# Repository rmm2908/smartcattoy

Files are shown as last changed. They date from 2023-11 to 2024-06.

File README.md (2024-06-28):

# SmartCatToy

… is a toy controlled via a webapp to entertain our feline friends during our absence.

The idea behind this project is to provide a cheap alternative to expensive toys, with which you can provide entertainment for lonley single cats in flats.

## Must Have

- Spherical Toy
    - Moves around
    - Can receive input via network
- mobile App
    - connect toy to mobile app
    - control toy remotely
    - provides autopilot mode
- Back End
    - receive Data from App
    - send Data to Mobile app
- Database
    - Store Data from Backend
- Infrastructure
    - Running nodejs
    - Running database
    - reachable via internet

## Nice to Have

- replace autopilot (random generator) via inteligent movement detection
- add tail to toy for more interaction
- add sounds to toy
- add camera feed to app
- login (Database necessary)

## Platform Overview

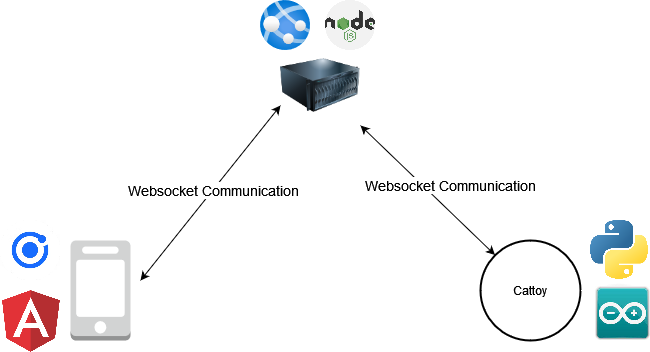
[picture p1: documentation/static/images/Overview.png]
Platform Overview
  

The client application is developed using Ionic 7 with Angular and can be deployed to iOS, Android and the Web.

The hardware toy is running a python script to receive data from the client and acts as the central inteligence hub of the hardware, housing the logic of the hardware and sends the commands over a Serial Interface to Arduino.

Arduino just receives the commands from python script on the Raspberry Pi and controls all sensors and motors.

Both the client application and the cattoy don't communicate directly to each other but to a server hosted on azure web application.

It is a NodeJS Express application that acts as an intermediary to establish connection between those two devices using WebSockets to enable low latency.

## Hardware Overview

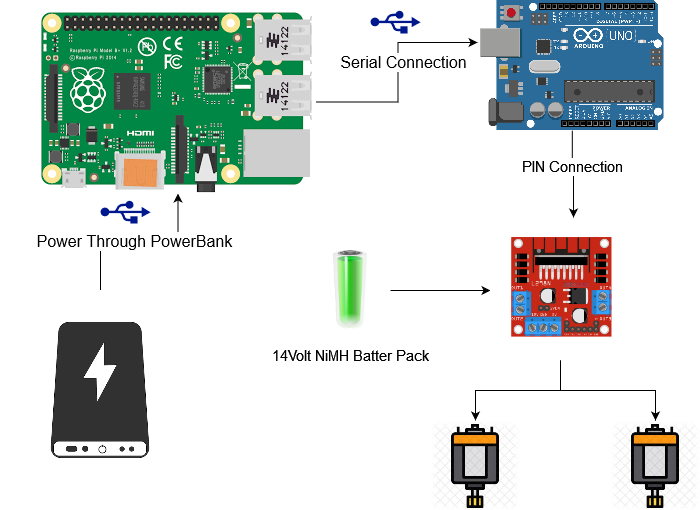
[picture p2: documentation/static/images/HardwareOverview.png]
Hardware Overview
  

A raspberry pi acts as the central logic hub, which is powered by a power bank.
It is directly connected to an Arduino Uno over a USB Serial Connection to establish bidirectional communication.

The Arudino receives all commands from the python script running on the raspberry to controll the motors attached to it. 
As the communication is bidirectional, it could send sensor data back to the raspberry, if those should be added.

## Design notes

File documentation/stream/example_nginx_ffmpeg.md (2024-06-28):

# Example setup for streaming web server
This example setup will provide the necessary configuration for a simple web server serving m3u8 video files using [nginx](https://nginx.org/en/).<br>
These instrunctions were last tested on a debian machine. Depending on which operating system you are using, some steps may vary.
## Setting up the web server
First, we will set up a nginx instance with which we will serve the video stream.<br>
### Install nginx
<b>Install nginx using apt</b><br>
``` sudo apt install nginx ```<br>
### Setup site
Once nginx is instaslled, only some basic configuration is necessary for a minimal nginx setup to provide a HLS stream. The configuration for nginx is located under "/etc/nginx". To serve the stream, we will create a new site under "/etc/nginx/sites-available/stream.config" using the following configuration:
```
server {
	listen 80 default_server;
	listen [::]:80 default_server;

	root /var/www/stream;

	index index.html index.htm index.nginx-debian.html;

	server_name _;

	location / {
		# CORS
		add_header 'Access-Control-Allow-Origin' '*' always;
		add_header 'Access-Control-Expose-Headers' 'Content-Length,Content-Range';
		add_header 'Access-Control-Allow-Headers' 'Range';

		types {
			application/vnd.apple.mpegurl m3u8;
			video/mp2t ts;
		}
		# First attempt to serve request as file, then
		# as directory, then fall back to displaying a 404.
		try_files $uri $uri/ =404;
		autoindex on;
	}
}
```
This configuration will a site on port 80 using the directory "/var/www/stream". In this directory, the video file for the stream should be placed.<br>
Different types for the video can be defined - by default, SmartCatToy uses m3u8.<br>
### Enable the site
To enable the site we just configured, we need to create a symbolic link to sites-enabled:
``` sudo ln -s /etc/nginx/sites-available/stream.conf /etc/nginx/sites-enabled/stream.conf ```<br>
After creating the link, nginx needs to be reloaded:<br>
``` sudo systemctl reload nginx ```
## Provide video resource for streaming
To provide a file that can be streamed via HLS from a camera installed on the toy, the toy needs to send a video stream to the server. For example, this could be achieved using [ffmpeg](https://ffmpeg.org/).
### Stream camera feed from toy to server
Using ffmpeg, the footage from an installed camera can be sent to the server. A [python script](../../raspberry/camera_client.py) running on the toy will send the camera footage to the server on port 8001 using UDP.
### Convert incoming stream to video file
On the server, we need to listen on this port and convert the incoming stream to a video file in the m3u8 format, so that it can be served using the nginx site we created.<br>
#### ffmpeg command to convert UDP stream to m3u8
This command will listen on the UDP port 8001 and convert the stream to a m3u8 and split the incoming frames into segments (.ts files):<br>
``` sudo ffmpeg -y -i udp://localhost:8001 -preset ultrafast -tune zerolatency -omit_video_pes_length 0 -g 90 -flags -global_header -fflags nobuffer -flags low_delay /var/www/stream/bucket/stream.m3u8 ```<br>
This command uses various parameters and presets to try to reduce the streaming delay caused by HLS streaming. Once the server starts to receive UDP packets on the specified port, ffmpeg will create a stream.m3u8 file and segment the incoming video feed into small .ts-files.
## Resulting HLS streaming resource
If the above instrunctions were all carried out, a video file will be created from the incoming camera feed and can be queried using HLS. If the exact configurations and folder structures were used, it will be available under ``` http://<server-address>/bucket/stream.m3u8 ```

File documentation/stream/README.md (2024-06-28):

# Stream
The SmartCatToy app provides the possibility of live streaming a camera feed from the toy.  It does this by querying a web server to stream a video using HLS (HTTP-Livestreaming). Therefore, a web server providing such a stream is needed for this feature to work.
## Requirements
* ### Web server
    A web server is needed to provide the video resource for the stream.
It is important that the video file can be accessed directly via URL (also consider CORS).
* ### Video ressource for streaming
    A video file in the correct format (default: m3u8) can be served through the web server to the app. SmartCatToy does this by sending the camera feed to the server using UDP. The server then converts the incoming UDP stream to the required video format.
### Example using nginx and ffmpeg
Instructions for setting up such a environment can be found [here](example_nginx_ffmpeg.md).

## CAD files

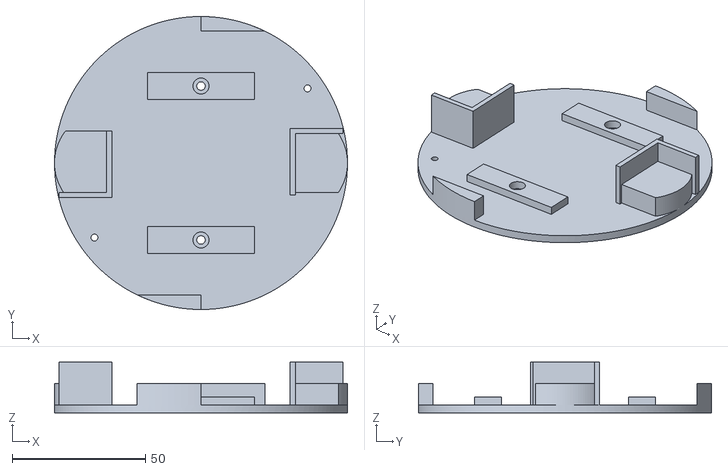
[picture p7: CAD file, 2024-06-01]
cad_models/board/version4/board_bot-Body.stl
110.0 x 110.0 x 19.0

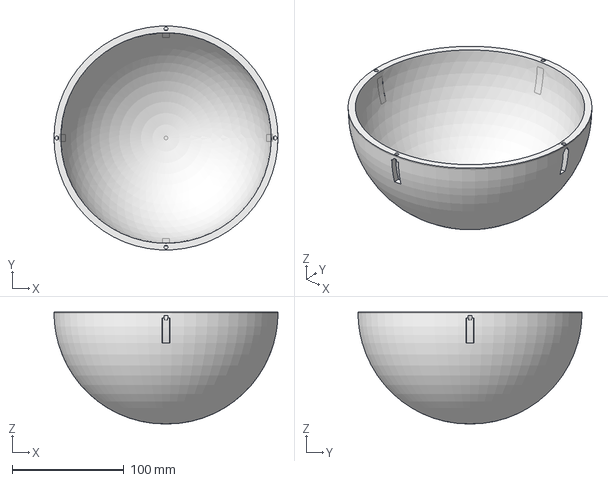
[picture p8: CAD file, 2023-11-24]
cad_models/sphere/version2/half_sphere.FCStd
200.0 x 199.9 x 100.0 mm

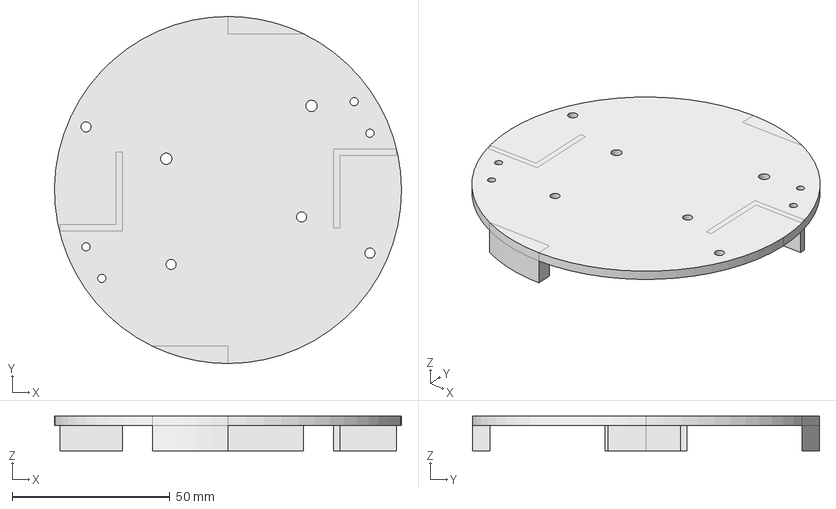
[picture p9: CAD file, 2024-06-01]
cad_models/board/version4/board_mid.FCStd
110.0 x 110.0 x 11.0 mm

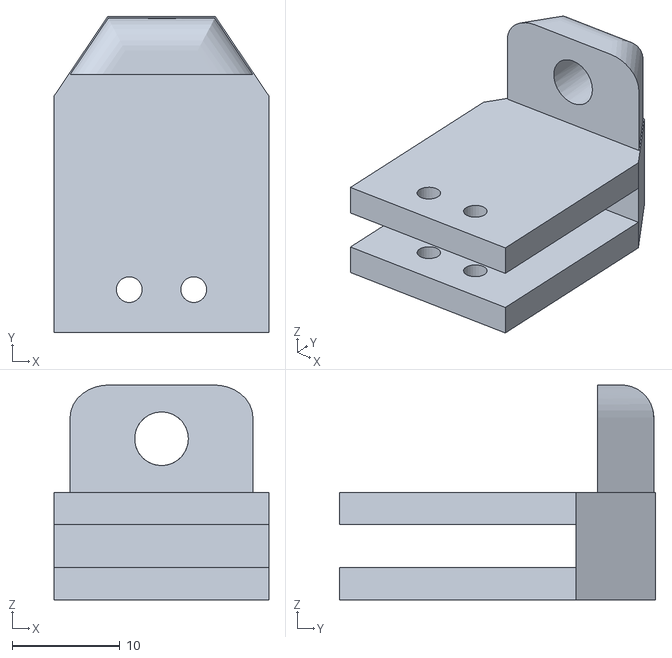
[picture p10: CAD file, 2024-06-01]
cad_models/board/version4/stabiliser_holder_neutral-Körper.stl
20.0 x 29.4 x 20.0

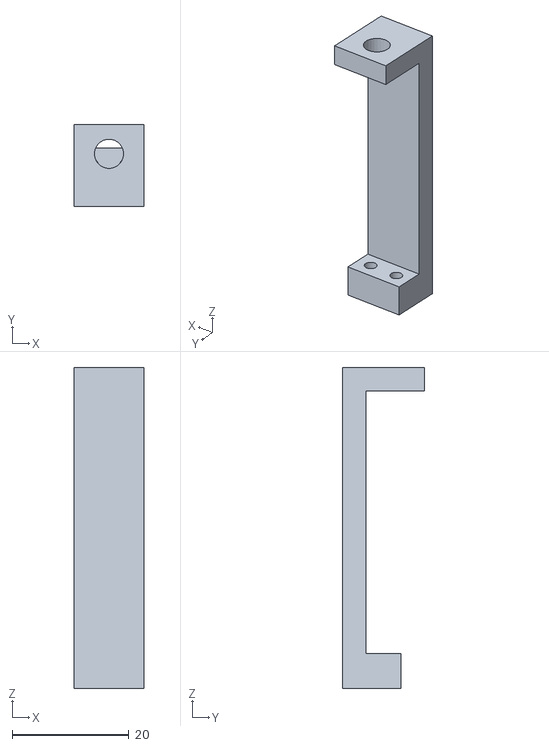
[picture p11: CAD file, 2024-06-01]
cad_models/board/version4/stabiliser_top-Body.stl
12.0 x 14.0 x 55.0

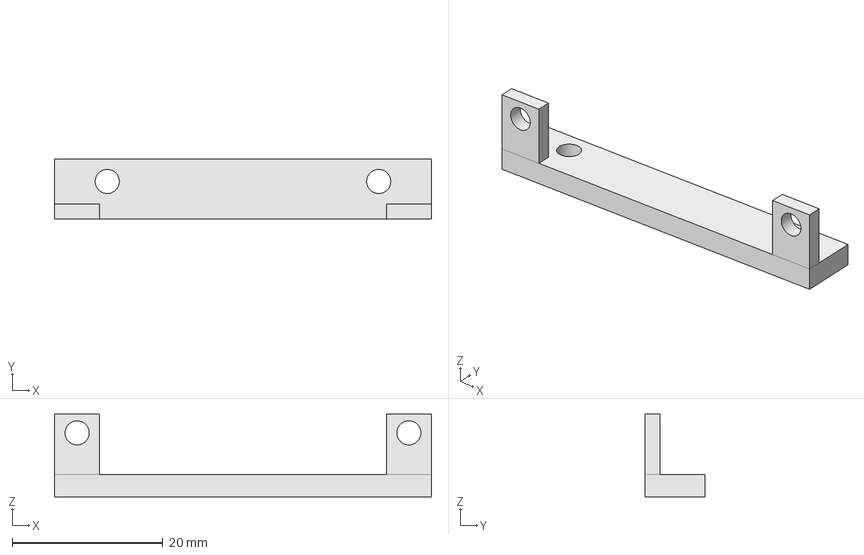
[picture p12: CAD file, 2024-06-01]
cad_models/board/version4/audio_holder_top.FCStd
50.0 x 8.00 x 11.0 mm

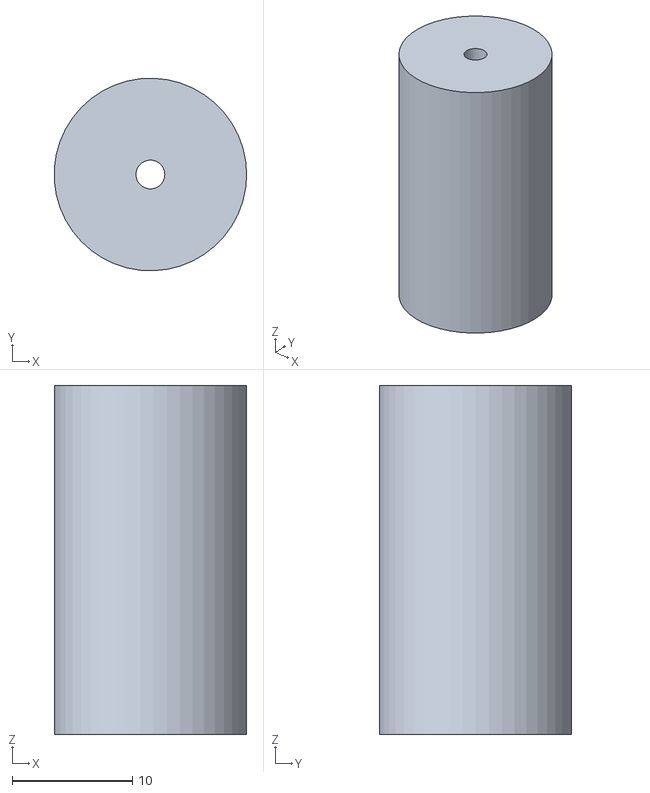
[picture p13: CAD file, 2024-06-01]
cad_models/board/version4/board_connector_top_mid-Body.stl
16.0 x 16.0 x 29.0

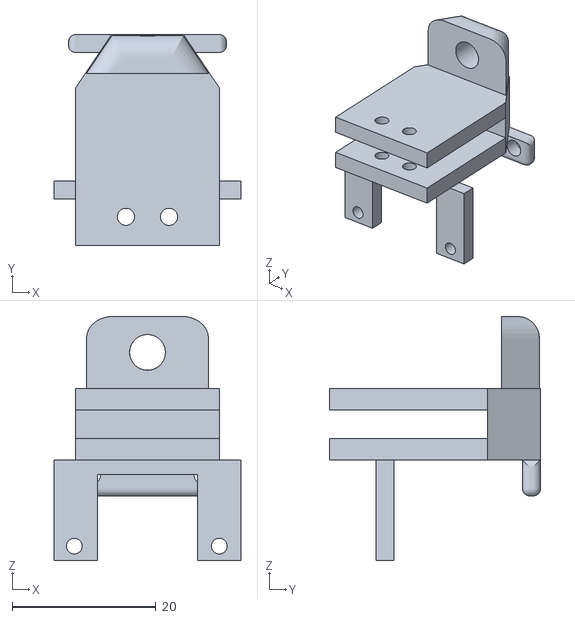
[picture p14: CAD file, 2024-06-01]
cad_models/board/version4/stabiliser_holder_sensors-Körper.stl
26.0 x 29.4 x 34.0

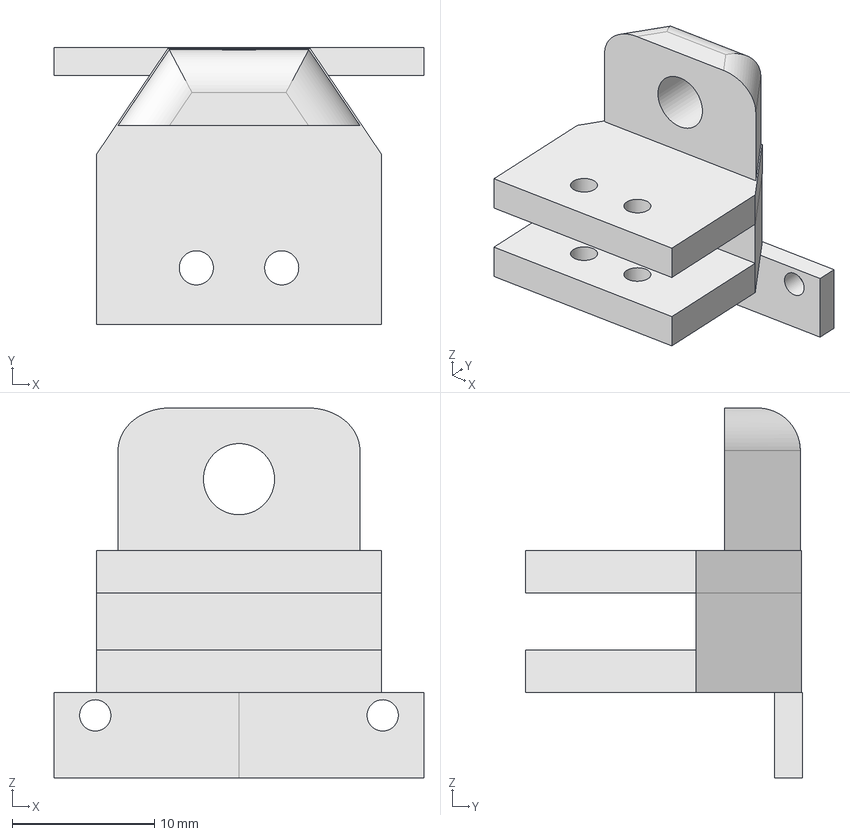
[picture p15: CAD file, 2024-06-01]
cad_models/board/version4/stabiliser_holder.FCStd
26.0 x 19.5 x 26.0 mm

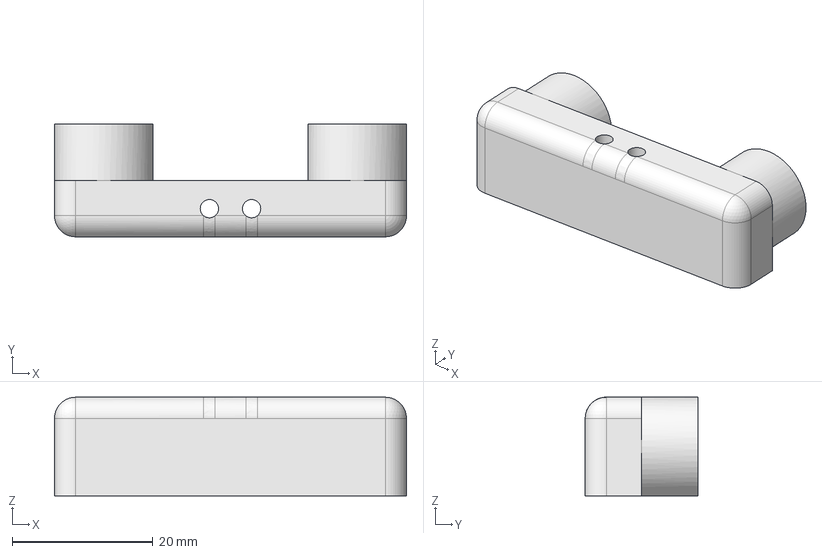
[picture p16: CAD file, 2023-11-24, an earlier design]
cad_models/board/version1/stabiliser_holder.FCStd
50.0 x 16.0 x 14.0 mm

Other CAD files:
cad_models/board/version4/stabiliser_holder_neutral.FCStd
cad_models/board/version4/stabiliser_holder-Body.stl
cad_models/board/version4/board_bot.FCStd
cad_models/board/version4/stabiliser_top.FCStd
cad_models/board/version4/board_connector_top_mid.FCStd
cad_models/board/version4/board_mid-Body.stl
cad_models/board/version4/stabiliser_holder_sensors.FCStd
cad_models/board/version2/board_bot.FCStd
cad_models/board/version1/adapted.FCStd
cad_models/board/version1/arduino_connector.FCStd
cad_models/board/version1/arduino_holder.FCStd
cad_models/board/version1/board_bot.FCStd
cad_models/board/version1/board_connector.FCStd
cad_models/board/version1/board_top.FCStd
cad_models/board/version1/cattoy2.FCStd
cad_models/board/version1/pad.FCStd
cad_models/board/version2/arduino_connector.FCStd
cad_models/board/version2/arduino_holder.FCStd
cad_models/board/version2/board_top.FCStd
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

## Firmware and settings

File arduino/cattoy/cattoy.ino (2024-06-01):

#include <Wire.h>
#include <VL6180X.h>

VL6180X sensor;

int ena = 11;
int in1 = 12;
int in2 = 10;

int enb = 5;
int in3 = 6;
int in4 = 7;
String input = "EMPTY";

int leftPower;
int leftReverse;
int rightPower;
int rightReverse;
int noUpdateCounter = 0;

char payload[64];

void setup() {
  Serial.begin(9600); 
  Wire.begin();

  sensor.init();
  sensor.configureDefault();
  sensor.setTimeout(500);

  pinMode(ena, OUTPUT);
  pinMode(in1, OUTPUT);
  pinMode(in2, OUTPUT);

  pinMode(enb, OUTPUT);
  pinMode(in3, OUTPUT);
  pinMode(in4, OUTPUT);
  
  }

int getIntFromString(String text) {
  return text.toInt();
}

void updateMotorPower(int leftPower, int rightPower) {

  if(leftPower > 255) {
    leftPower = 255;
  } 

  if(leftPower < 0) {
    leftPower = 0;
  }

  if(rightPower > 255) {
    rightPower = 255;
  }

  if(rightPower < 0) {
    rightPower = 0;
  }
  
  analogWrite(ena, leftPower);
  analogWrite(enb, rightPower);
}

void updateMotorDirection(int leftReverse, int rightReverse) {

  if(leftReverse == 0) {
    //Left
    digitalWrite(in1, HIGH);
    digitalWrite(in2, LOW);
  }

  if(leftReverse == 1) {
    //Left
    digitalWrite(in1, LOW);
    digitalWrite(in2, HIGH);
  }
  
  if(rightReverse == 0) {
    //Right
    digitalWrite(in3, LOW);
    digitalWrite(in4, HIGH);
  }

  if(rightReverse == 1) {
    //Right
    digitalWrite(in3, HIGH);
    digitalWrite(in4, LOW);
  }
}

void loop() {

  //Input -> 255,0,255,0 -> turned to 255 | 0 | 255 | 0
  if (Serial.available() > 0) {
    Serial.readStringUntil( '\n' ).toCharArray(payload, 64);
    leftPower = getIntFromString(strtok(payload, ","));
    leftReverse = getIntFromString(strtok(NULL, ","));
    rightPower = getIntFromString(strtok(NULL, ","));
    rightReverse = getIntFromString(strtok(NULL, ","));

    updateMotorPower(leftPower, rightPower);
    updateMotorDirection(leftReverse, rightReverse);
    noUpdateCounter = 0;
  } else {
    noUpdateCounter = noUpdateCounter + 1;
  }

  Serial.print(sensor.readRangeSingleMillimeters());
  //if (sensor.timeoutOccurred()) { Serial.print(" TIMEOUT"); }
  Serial.println();

  if(noUpdateCounter > 15) {
    updateMotorPower(0, 0);
  }

  delay(50);
}

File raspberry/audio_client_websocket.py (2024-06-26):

import websockets
import pygame
import asyncio
import json
import time
import os
import tempfile
import base64

# Initialize the pygame mixer for audio operations.
pygame.mixer.init()

# Get the event loop for the current context.
loop = asyncio.get_event_loop()

def play_audio(audio_file_path):
    """
    Load and play an audio file using pygame.

    Parameters:
        audio_file_path (str): The file system path to the audio file.
    """
    pygame.mixer.music.load(audio_file_path)
    pygame.mixer.music.play()

async def unload_audio():
    """
    Asynchronously monitors and unloads the audio track once it finishes playing.
    Continuously checks every second to see if the audio is still playing.
    """
    while True:
        await asyncio.sleep(1)
        if not pygame.mixer.music.get_busy():
            try:
                pygame.mixer.music.unload()
                print("Audio unloaded")
                break
            except Exception as e:
                print(f"Error unloading audio: {e}")
                break

async def receive_file(fileName, fileData):
    """
    Receives a base64 encoded file, decodes it, and writes it to the file system.

    Parameters:
        fileName (str): The name of the file to save.
        fileData (str): Base64 encoded data of the file.
    """
    if os.path.exists(fileName):
        os.remove(fileName)
    with open(fileName, "wb") as file:
        file.write(base64.b64decode(fileData))
        print(f"File received: {fileName}")

def handle_audio_command(content_obj):
    """
    Handles the command to play audio if specified in the message object.

    Parameters:
        content_obj (dict): A JSON object containing potential audio commands.
    """
    if "play_audio" in content_obj:
        try:
            audio_FileName = sanitize_filename(content_obj["play_audio"])
            print(f"Received audio file: {audio_FileName}")
            audio_path = os.path.join(os.curdir, audio_FileName)
            if os.path.exists(audio_path):
                play_audio(audio_path)
                print(f"Playing audio: {audio_path}")
        except ValueError as e:
            print(f"Error: {e}")

def get_rotating_filename(base_path, base_name, extension, limit=10):
    """
    Generates a rotating filename within a specified limit to avoid file overwrites.

    Parameters:
        base_path (str): The directory path where the file will be saved.
        base_name (str): The base name for the file.
        extension (str): The file extension.
        limit (int): The maximum number of files before the index resets.
    
    Returns:
        str: The full path to the file with the generated name.
    """
    index_file_path = os.path.join(base_path, f"{base_name}_index.txt")
    
    if os.path.exists(index_file_path):
        with open(index_file_path, 'r') as file:
            last_index = int(file.read().strip())
    else:
        last_index = 0

    next_index = (last_index % limit) + 1

    with open(index_file_path, 'w') as file:
        file.write(str(next_index))

    filename = f"{base_name}_{next_index}.{extension}"
    return os.path.join(base_path, filename)

def sanitize_filename(filename):
    """
    Sanitizes the filename, removing unsafe characters and enforcing restrictions on length and file extensions.

    Parameters:
        filename (str): The filename to sanitize.

    Returns:
        str: The sanitized filename if valid, raises ValueError otherwise.

    Raises:
        ValueError: If the filename contains unauthorized extensions or exceeds length constraints.
    """
    allowed_extensions = {'.mp3', '.wav'}
    
    filename = filename.strip()
    filename = filename.replace('/', '').replace('\\', '').replace('\0', '')
    filename = os.path.basename(filename)
    
    root, ext = os.path.splitext(filename)
    if ext.lower() not in allowed_extensions:
        raise ValueError(f"Unauthorized file extension: {ext}")
    
    max_length = 50
    if len(filename) > max_length:
        raise ValueError(f"Filename too long. Max length is {max_length} characters.")
    
    return filename

async def handler():
    """
    Main handler function for WebSocket communication and processing received commands.

    Establishes a WebSocket connection to the specified URI and listens for incoming messages,
    handling audio playback and file transfer operations based on the content of the messages.
    """
    uri = "ws://localhost:3000"
    async with websockets.connect(uri, max_size=20000000) as websocket:
        await websocket.send("{\"request\": \"message from raspberry audio client\"}")
        done = False
        while not done:
            time.sleep(10/1000)
            message = await websocket.recv()
            print(message)
            if isinstance(message, str):
                try:  
                    parsed_message = json.loads(message)
                    if "play_audio" in parsed_message:
                        handle_audio_command(parsed_message)
                        asyncio.create_task(unload_audio())
                    elif "operation" in parsed_message and parsed_message["operation"] == "file_transfer":
                        file_name = get_rotating_filename(os.curdir, "audioFile", "mp3")
                        await receive_file(file_name, parsed_message["file"])
                        play_audio(file_name)
                        asyncio.create_task(unload_audio())
                    elif "stop_audio" in parsed_message:
                        pygame.mixer.music.stop()
                        print("Audio stopped")
                except ValueError:
                    print("Could not parse message")
                    continue

asyncio.run(handler())

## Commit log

2023-10-30 add cad model and arduino script
    [cattoy2.FCStd]
2023-10-31 add raspberry script
2023-11-24 update with new cad model versions
    [adapted.FCStd, arduino_connector.FCStd, arduino_holder.FCStd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]
2023-11-24 update with the latest board version
    [arduino_connector.FCStd, arduino_holder.FCStd, board_bot.FCStd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]
2023-11-26 update arudino script; raspberry server; add app
    [adapted.FCStd, arduino_connector.FCStd, arduino_holder.FCStd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]
2023-11-26 update raspberry script; deploy to android;
2023-12-23 add autopilot; add reconnect button; switch buttons with sliders for controls
2024-06-01 update board to hold camera and tof sensor; update autopilot to utilize TOF sensor
    [audio_holder_top.FCStd, audio_holder_top.stl, board_bot-Body.stl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]
2024-06-01 Feature/audio (#15)
    * Implemented audioclient
    - Can play static audio files
    - Can also receive audio files and play them
    * Implemented Ionic app funtion
    - Added new buttons and file upload in the app
    - Made the audioClient safer for wrong filenames
    - Added sound queue, lets sound finish before it plays the next
    [audio_client_websocket.py]
2024-06-01 Feature/audio (#16)
    * Update README.md
    ---------
    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
    [audio_client_websocket.py]
2024-06-02 fix autopilot bugs after test drive
    [client_websocket.py]
2024-06-02 Feature/audio (#19)
    * - Changed the unloading flow
    - Added stop sound button
    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
    [audio_client_websocket.py]
